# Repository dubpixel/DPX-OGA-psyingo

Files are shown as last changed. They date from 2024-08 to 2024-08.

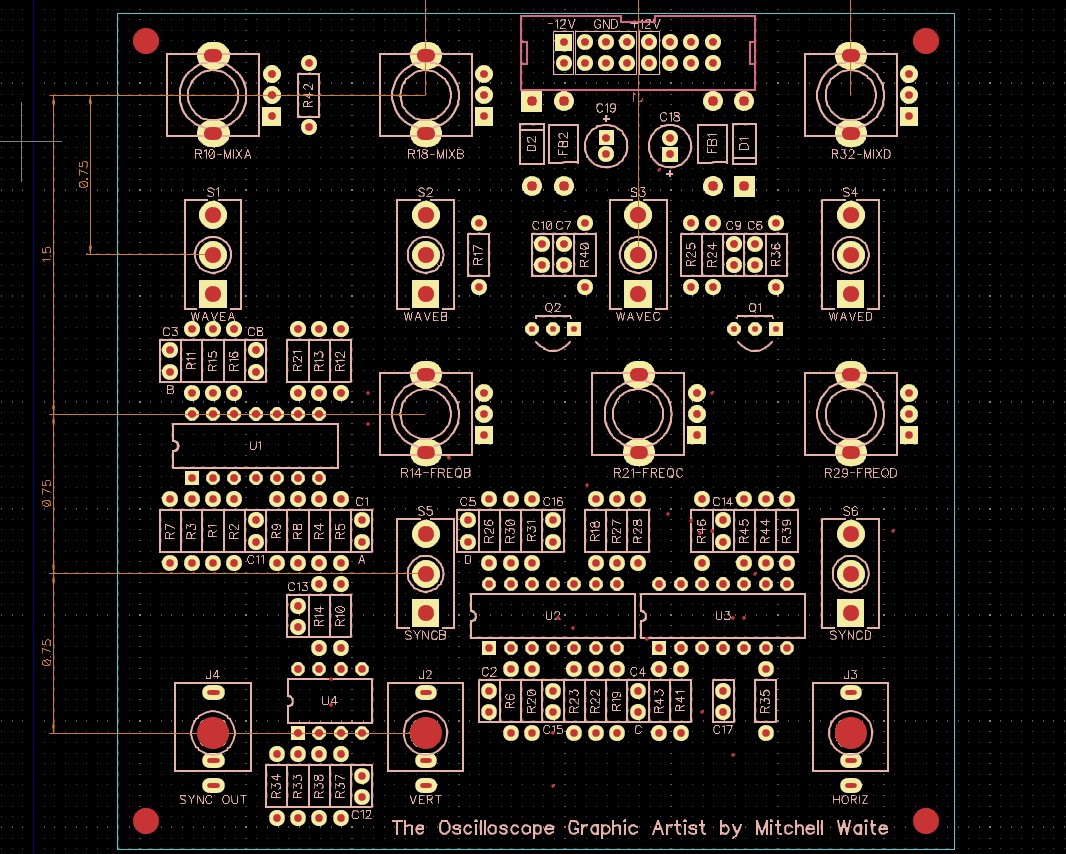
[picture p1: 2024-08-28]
doc/board_Screenshot_parts_placement.jpg

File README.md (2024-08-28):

# OGA

The Oscilloscope graphic artist is a project that was originally designed by Mitchell Waite in the November 1975 issue of Popular Electronics. 
I have made the design in to a PCB project with gerber files and a bill of materials for anyone to make. 
Please do not sell these for profit.
Contact me if you would like me to lead a workshop.
If you host your own workshop please credit me, Phil Baljeu. IG @pbalpbal [http:](https://www.instagram.com/pbalpbal/)https://www.instagram.com/pbalpbal/

#DPX
This fork includes a new panel + aims to add additional refinements towards using the device directly with ILDA lasers

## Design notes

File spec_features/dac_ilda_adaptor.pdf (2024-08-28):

This tutorial walks you through building a simple DAC_ILDA adaptor for converting audio signals sent from a multi-channel DAC (http://www.expert-sleepers.co.uk/siwacompatibility.html) (Digital Analog Converter) to an ILDA Interface (https://www.laserworld.com/en/show-laser-light-faq/glossary-definitions/79-i/1316-ilda-eng.html) (International Laser Display Association standard used for laser light systems) to control the XY-axis, RGB and intensity of the beam.

Warning: This is an amateur guide for interfacing an audio DAC with IDLA. Use at your own (+ laser) risk – each laser spec may have an custom requirements for voltage/frequency limiting needs. Be careful.

# DAC_ILDA Adaptor

v 0.1.2 // Download PDF (https://github.com/ffd8/dac_ilda/raw/master/dac_ilda_adaptor.pdf)

# Abstract

# Wiring Diagram

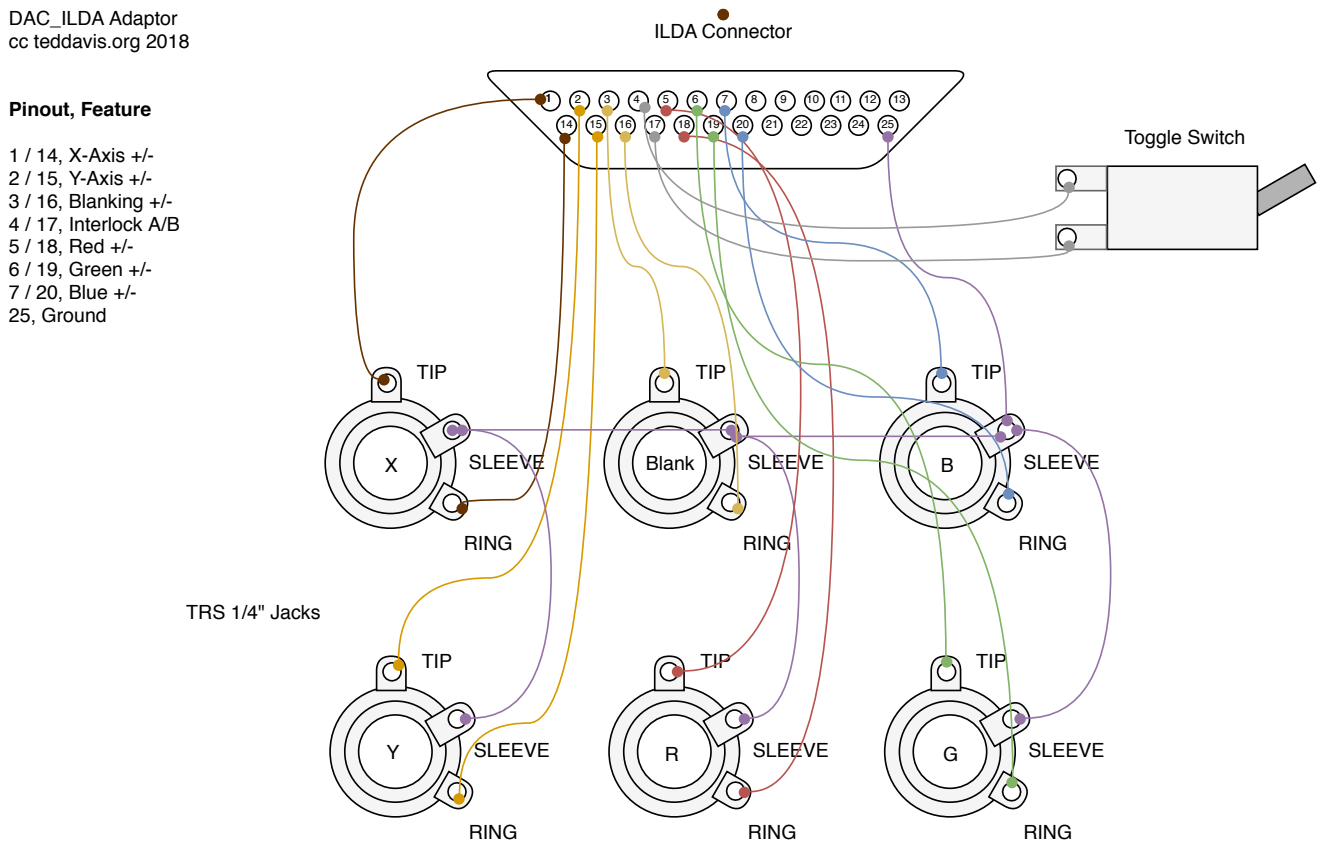
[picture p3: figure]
TIP; RING; Blank; SLEEVE; DAC_ILDA Adaptor cc teddavis.org 2018; Pinout, Feature; 1 / 14, X-Axis +/- 2 / 15, Y-Axis +/- 3 / 16, Blanking +/- 4 / 17, Interlock A/B 5 / 18, Red +/- 6 / 19, Green +/- 7 / 20, Blue +/- 25, Ground; ILDA Connector; TRS 1/4" Jacks; Toggle Switch

ILDA female connector (DB25)
6x 1/4" balanced (TRS) female jacks 6x 1/4" balanced (TRS) cables
1x toggle switch (on/off)
Various colored wires (jumper cables) Project box
Soldering iron + wire
Wirecutters

RGB Laser with ILDA interface
ILDA cable
DAC (multi-channel, balanced, ideally DC-Coupled outputs) Computer for producing audio signals

# Requirements

## Adaptor

## Setup

# Instructions

## 1 – Prep

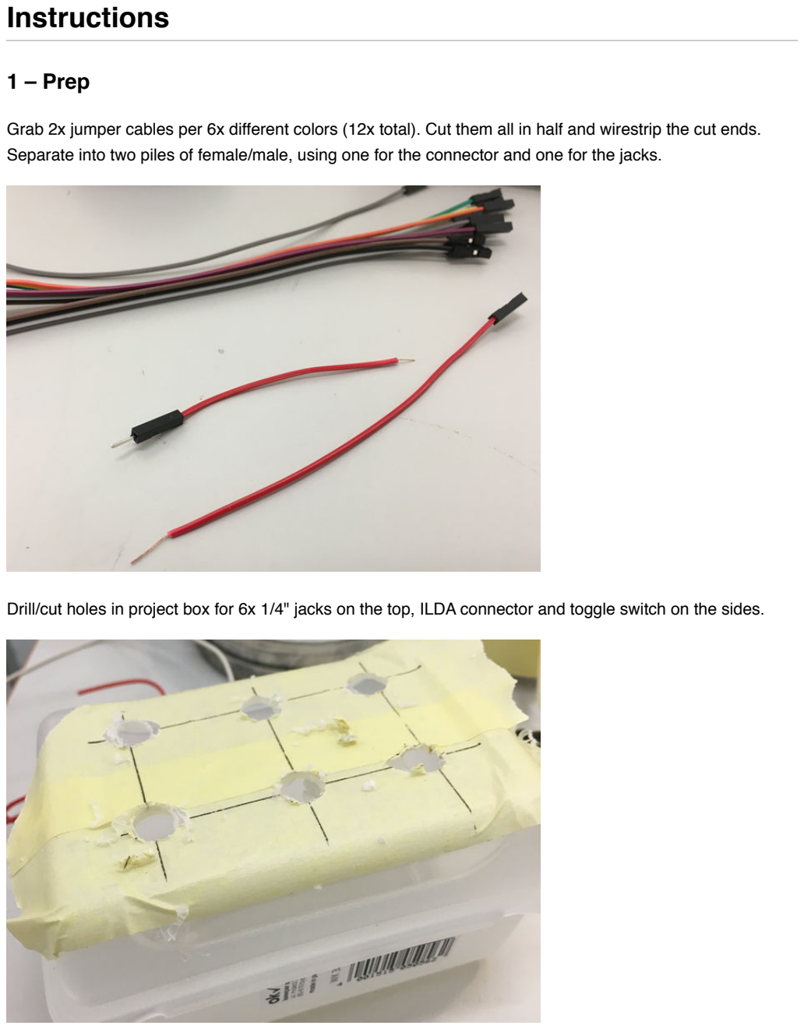
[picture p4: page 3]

Grab 2x jumper cables per 6x different colors (12x total). Cut them all in half and wirestrip the cut ends. Separate into two piles of female/male, using one for the connector and one for the jacks.

Drill/cut holes in project box for 6x 1/4" jacks on the top, ILDA connector and toggle switch on the sides.

Feature | Pins | Comment
X-Axis + / - | 1 / 14 | Horizontal movement, 10V
Y-Axis + / - | 2 / 15 | Vertical movement, 10V
Blanking + / - | 3 / 16 | Beam intensity, 5V
Interlock A / B | 4 / 17 | Enables output when joined
Red + / - | 5 / 18 | Red mixture, 5V
Green + / - | 6 / 19 | Green mixture, 5V
Blue + / - | 7 / 20 | Blue mixture, 5V
Ground | 25 | Connected to all jacks sleeve
Z-Axis | 11 / 24 | For DMX? See Blanking.

Note, 'Blanking' seems to be done via RGB values, rather than these ILDA pins.

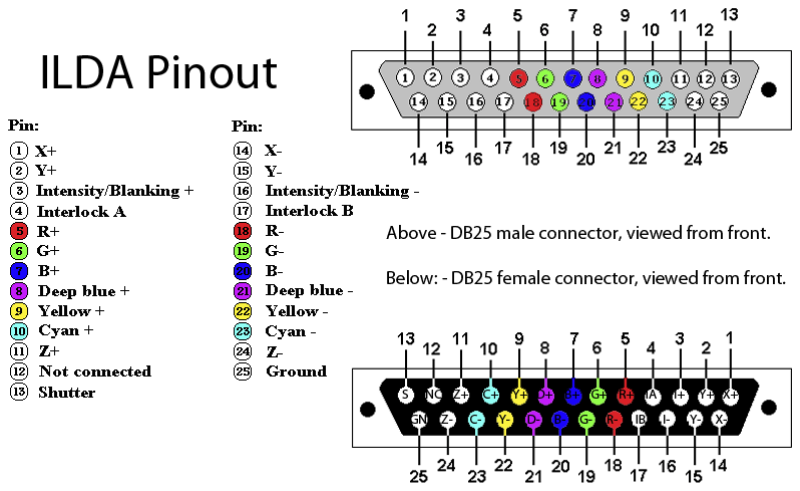
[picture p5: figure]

ILDA Pinout Source (https://vuo.org/comment/3145#comment-3145)

## 2 – ILDA Interface

Soldering paired color jumper cables to pins:

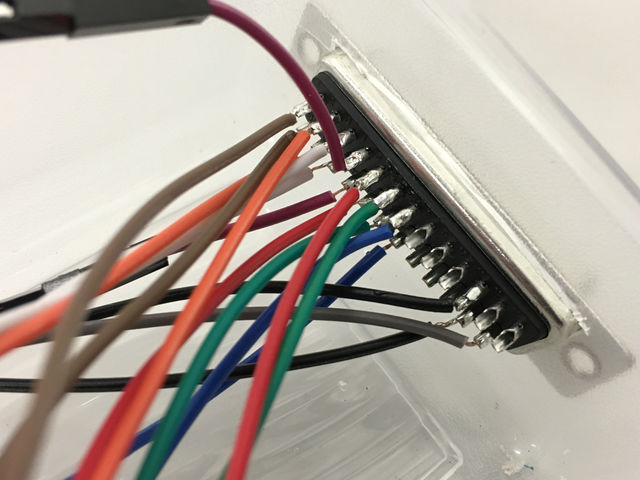
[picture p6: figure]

Diagram shows female ILDA connector from front, so flip pins horizontally when soldering to the back! I've already made that mistake for you...

Use different colored jumper cables per feature (8 total) to the diagram for easily identifying and patching the jacks to pins.

I wired jumpers to the Z-Axis pins (11/24), but not yet sure if they're needed.

Interlock A / B is a safety mechanism that only allows the laser to work if they're connected. I recommend using a basic toggle switch between these two pins.

Notes

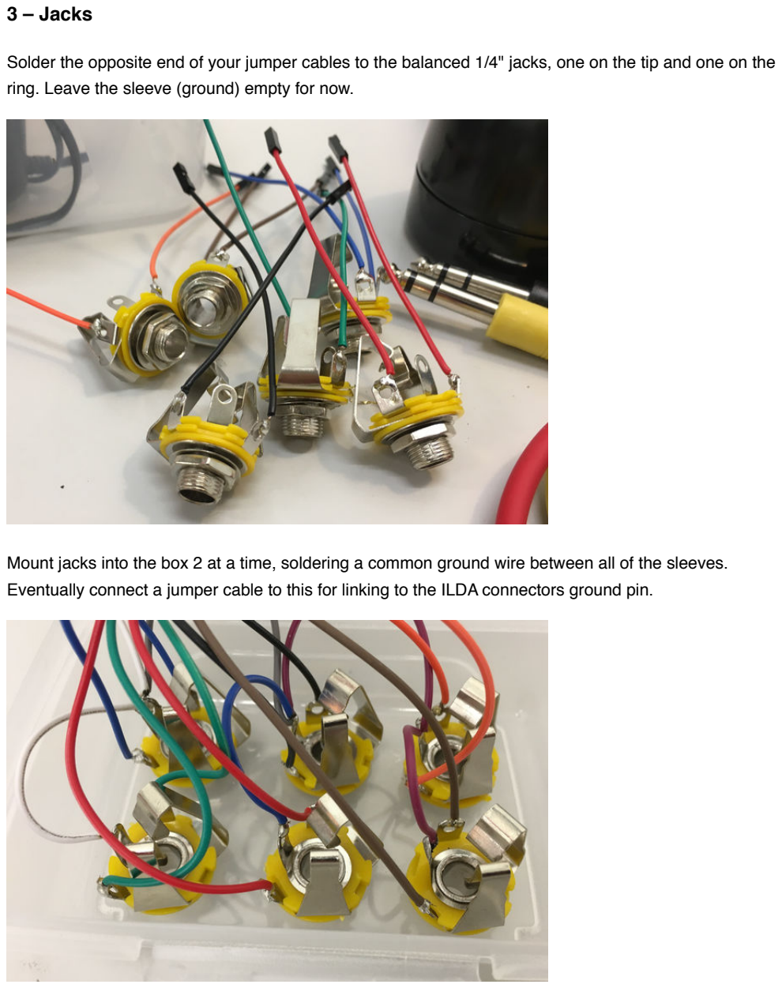
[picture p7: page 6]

Solder the opposite end of your jumper cables to the balanced 1/4" jacks, one on the tip and one on the ring. Leave the sleeve (ground) empty for now.

Mount jacks into the box 2 at a time, soldering a common ground wire between all of the sleeves. Eventually connect a jumper cable to this for linking to the ILDA connectors ground pin.

### 3 – Jacks

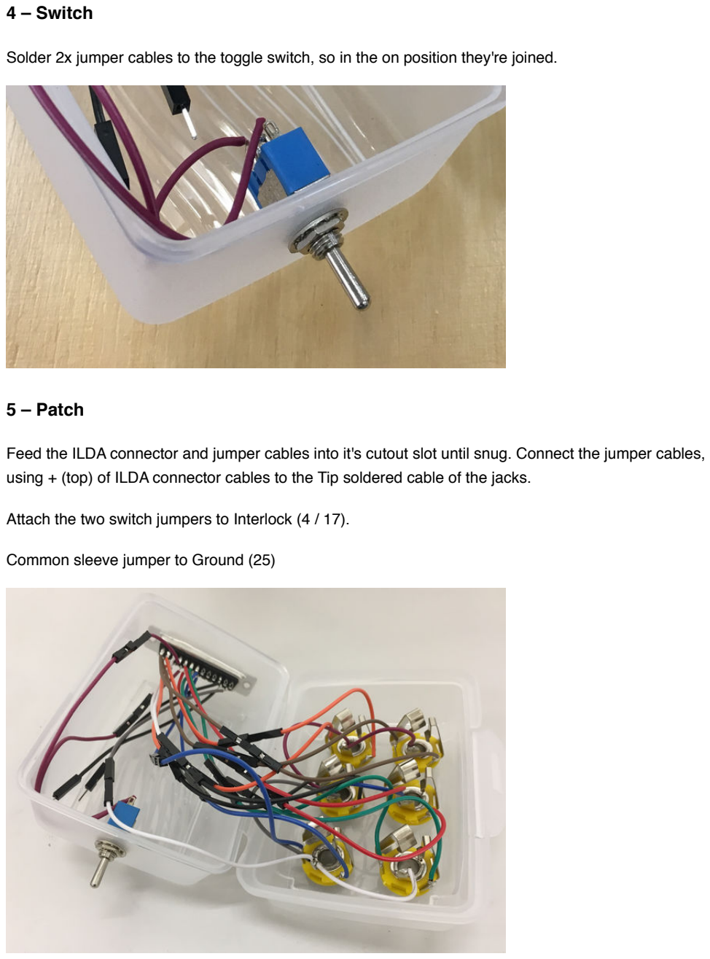
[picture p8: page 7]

Solder 2x jumper cables to the toggle switch, so in the on position they're joined.

Feed the ILDA connector and jumper cables into it's cutout slot until snug. Connect the jumper cables, using + (top) of ILDA connector cables to the Tip soldered cable of the jacks.

Attach the two switch jumpers to Interlock (4 / 17).

Common sleeve jumper to Ground (25)

### 4 – Switch

### 5 – Patch

Hook up your DAC » jacks + ILDA » laser and away you go!

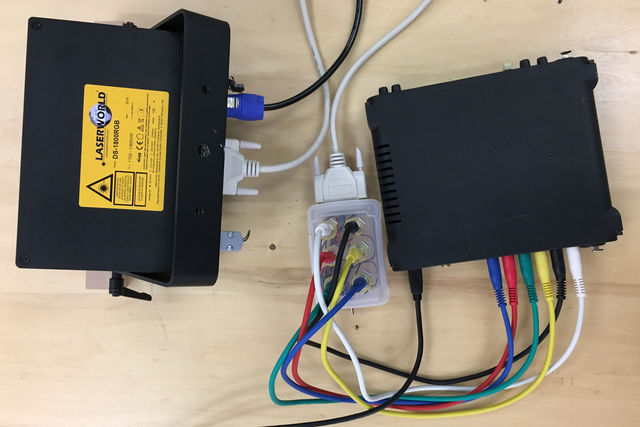
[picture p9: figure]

Here's a few tools to explore – some specific for laser, others for XY vector graphics +/- RGB capabilities:

Tool | Environment | OS | Cost | Realtime
LaserBoy (http://laserboy.org/) | Application | Windows | Free | -
LaserShow- Gen (http://pages.bitlasers.com/lasershowgen/) | Application | MacOS, Windows | Free Limited, $29.90 for Pro | √
Spaghetti Laser Show (http://www.spaghettilasershow.com/) | Application | Windows | $89.00 | √
LWave (https://www.photonlexicon.com/forums...896#post345896) | Application | Windows | Free | -
Tool | Environment | OS | Cost | Realtime | Laser
XYscope (http://teddavis.org/xyscope/) | Processing | MacOS, Windows, Linux | Free | √ | √
Vector Synthesis (http://macumbista.net/?page_id=4869) | PureData | MacOS, Windows, Linux | Free | √ | √
ReWereHere (http://i.m.klif.tv/rewerehere/) | Max/MSP | MacOS, Windows | Free | √ | √
OsciStudio (https://oscilloscopemusic.com/oscistudio.php) | Application | MacOS, Windows | €34 | √ | -

# Software

### Laser Specific

### Vector to Audio

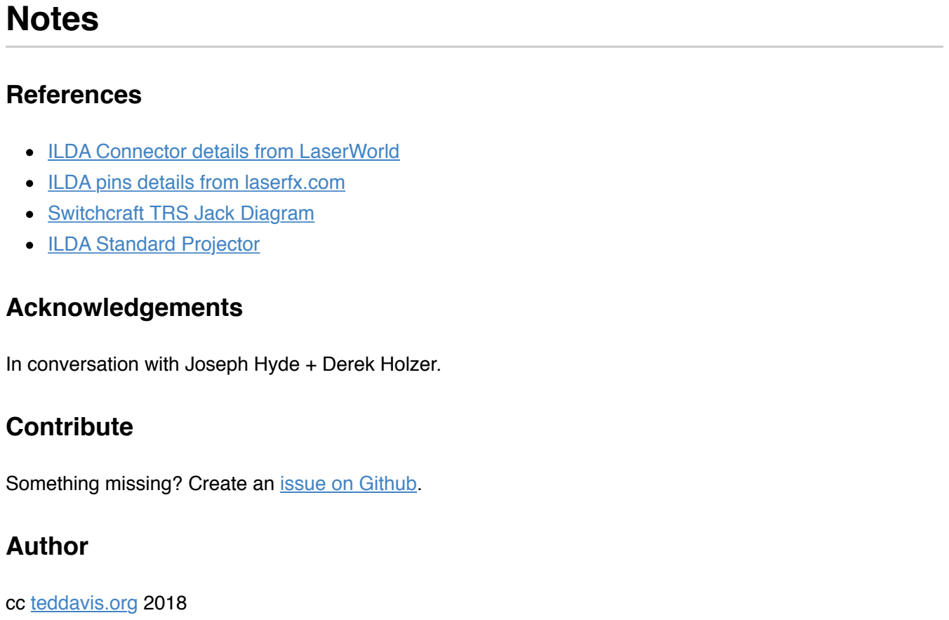
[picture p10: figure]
ILDA Connector details from LaserWorld; ILDA pins details from laserfx.com; Switchcraft TRS Jack Diagram; ILDA Standard Projector; cc teddavis.org 2018; Notes; References; Acknowledgements; Contribute; Author

In conversation with Joseph Hyde + Derek Holzer.

Something missing? Create an issue on Github. (https://github.com/ffd8/dac_ilda/issues)

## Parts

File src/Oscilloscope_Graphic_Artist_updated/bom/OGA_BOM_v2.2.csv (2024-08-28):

Ref | Value | Name | MFG | QTY | TAYDA | MOUSER | MOUSER ALT |  | Thonk | note | Lead Spacing
C1, C3 | 47n | CAP100 |  | 2 |  | 594-K473K20X7RH53H5 |  |  | XX | MLCC | 2.5
C2, C4, C10 | 1n | CAP100 |  | 3 |  | 594-K102K10X7RH5UL2 | 594-D102K29X5FL63L6R |  | XX |  | 2.5
C5, C6, C7, C8, C11, C12, C13, C14, C15, C16, C17 | 100n | CAP100 |  | 11 |  | 594-K104K15X7RF5TH5 |  |  | XX |  | 2.5
C9 | 10n | CAP100 |  | 1 |  | 594-K103K10X7RF5UL2 | 594-S103M47Z5UN63J7R |  | XX |  | 2.5
C18, C19 | 10u 25V | EC80-5 |  | 2 |  | 667-ECA-1EM100I |  |  | XX |  | 2.5
D1, D2 |  | 1N4001 |  | 2 |  | 625-1N4001-E3/73 |  |  | XX
FB1, FB2 | 68R | Ferrite Bead | Fair-Rite | 2 |  | 623-2743001112LF |  |  | XX
J1 |  | EUROPWR16 |  | 1 | A-2956 | 710-61201621621 |  |  | XX
Q1, Q2 |  | 2N3819 | ON Semiconductor | 2 |  | 610-2N3819 |  |  | XX
R1, R3, R7, R11, R13, R17, R19, R26, R28, R30, R33, R34, R35, R37, R38, R39, R41, R42, R43, R44, R45, R46 | 10K | RES300 |  | 22 | A-2203 | 660-MF1/4DCT52R1002F | 660-MF1/4DCT52A1002F |  | XX |  | 7.5
R2, R12, R27 | 20K | RES300 |  | 3 |  | 660-MF1/4DCT52R2002F | 660-MF1/4DCT52A2002F |  | XX |  | 7.5
R4, R25 | 4.7K | RES300 |  | 2 |  | 660-MF1/4DCT52R4701F | 660-MF1/4DC4701F |  | XX |  | 7.5
R5, R6, R9, R10, R14, R18, R21 | 1K | RES300 |  | 7 | A-2200 | 660-MF1/4DCT52R1001F |  |  | XX |  | 7.5
R8 | 120K | RES300 |  | 1 |  | 660-MF1/4DCT52R1203F |  |  | XX |  | 7.5
R15 | 24K | RES300 |  | 1 |  | 660-MF1/4DCT52R2402F |  |  | XX |  | 7.5
R16, R23, R31 | 100K | RES300 |  | 3 |  | 660-MF1/4D52R1003F |  |  | XX |  | 7.5
R20 | 15K | RES300 |  | 1 |  | 660-MF1/4DCT52R1502F |  |  | XX |  | 7.5
R22 | 2.7K | RES300 |  | 1 |  | 660-MF1/4DCT52R2701F |  |  | XX |  | 7.5
R24 | 47K | RES300 |  | 1 | A-2279 | 660-MF1/4DCT52R4702F |  |  | XX |  | 7.5
R36, R40 | 470K | RES300 |  | 2 | A-2180 | 660-MF1/4DCT52R4703F |  |  | XX |  | 7.5
R10-MIXA, R18-MIXB, R32-MIXD | B10K | ALPHA9V | Alpha | 3 | A-5531 | 652-PTV09A4020SB103 | 311-1940F-15R1-B10K |  | alpha 9mm pots vertical | linear
R14-FREQB, R21-FREQC, R29-FREQD | 1M | ALPHA9V | Alpha | 3 |  | 652-PTV09A4020SB105 | 317-3090F-B1M |  | alpha 9mm pots vertical | linear?
S1, S2, S3, S4, S5, S6 | WAVEA-D, SYNC B-D | 7101K2CBE | C&K | 6 |  | 612-100-A1421 | 612-100-A1122 | 611-7101-002 | DWB1 | og part specd here seems wrong - k2 Is wrong toggle type-
U1, U2, U3 |  | TL074J | Texas Instruments | 3 |  | 595-TL074CN | 595-TL074CN |  | xx
U4 |  | TL072P | Texas Instruments | 1 |  | 595-TL072CP | 595-TL072CP |  | xx
J2 | VERT | WQP-PJ398SM | Wenzhou QingPu Electronics Co., Ltd | 1 | A-2563 | XX |  |  | THONKICONN NEW - PJ398SM
J3 | HORIZ | WQP-PJ398SM | Wenzhou QingPu Electronics Co., Ltd | 1 | A-2563 | XX |  |  | THONKICONN NEW - PJ398SM
J4 | SYNC OUT | WQP-PJ398SM | Wenzhou QingPu Electronics Co., Ltd | 1 | A-2563 | XX |  |  | THONKICONN NEW - PJ398SM

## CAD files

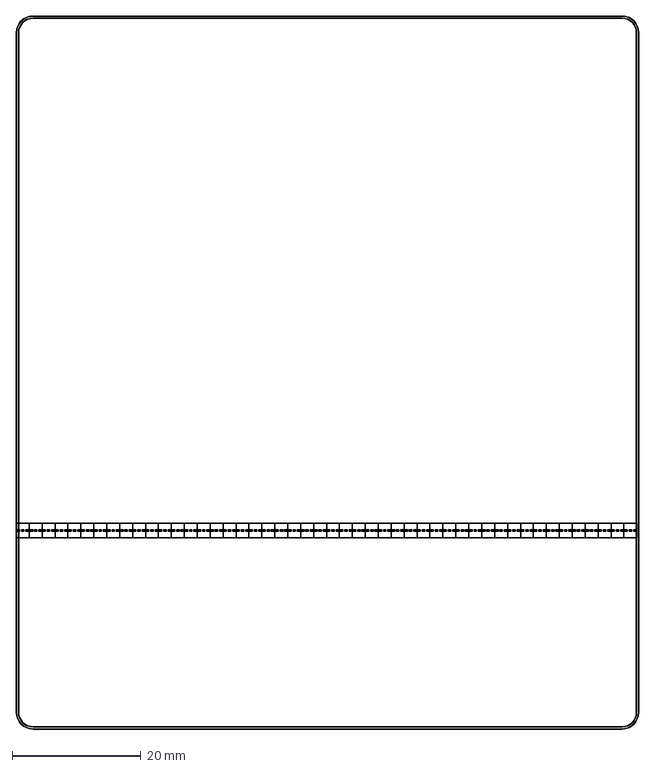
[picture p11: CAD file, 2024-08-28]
src/Oscilloscope_Graphic_Artist_Panel/DPX_v002/design/artwork/dxf_layer/004_oga_border.dxf
96.6 x 110.7 mm

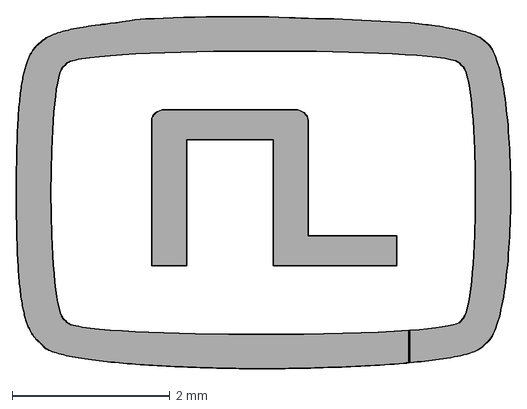
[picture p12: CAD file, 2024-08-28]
src/Oscilloscope_Graphic_Artist_Panel/DPX_v002/design/artwork/FRAME_TEST_1.dxf
6.27 x 4.47 mm

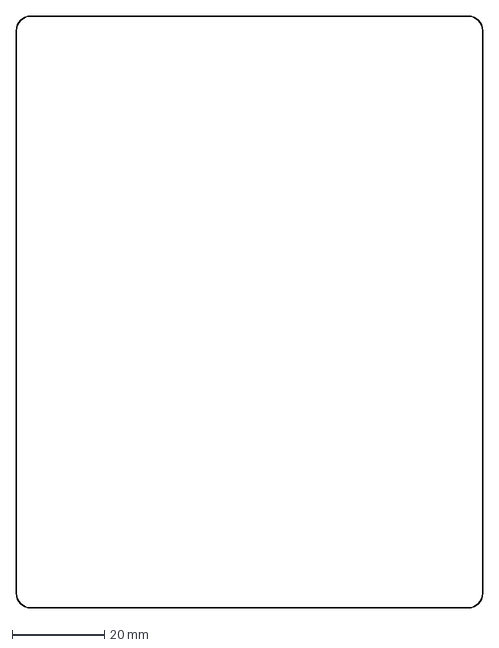
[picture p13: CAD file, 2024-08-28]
src/Oscilloscope_Graphic_Artist_Panel/DPX_v002/design/artwork/dxf_layer/001_oga_panel_2.dxf
101.3 x 128.5 mm

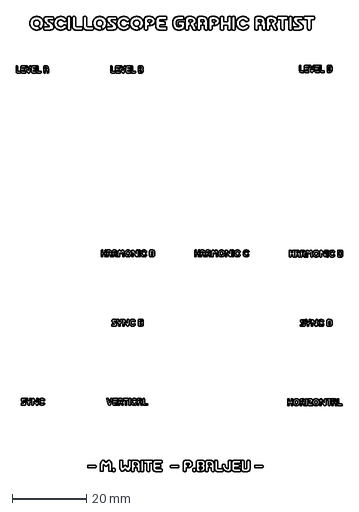
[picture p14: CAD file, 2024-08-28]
src/Oscilloscope_Graphic_Artist_Panel/DPX_v002/design/artwork/dxf_layer/005_oga_txt.dxf
87.8 x 122.2 mm

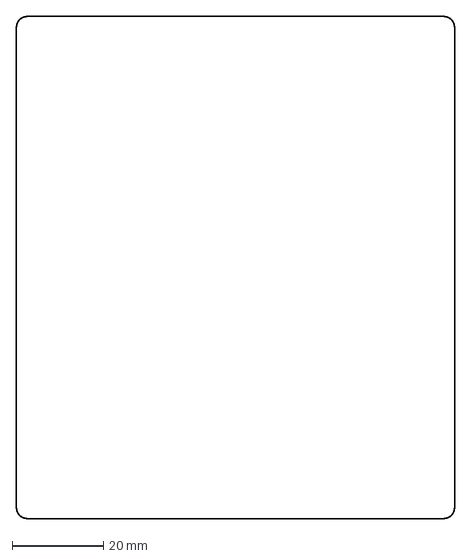
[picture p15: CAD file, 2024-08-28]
src/Oscilloscope_Graphic_Artist_Panel/DPX_v002/design/artwork/dxf_layer/004_oga_border_line.dxf
96.2 x 110.3 mm

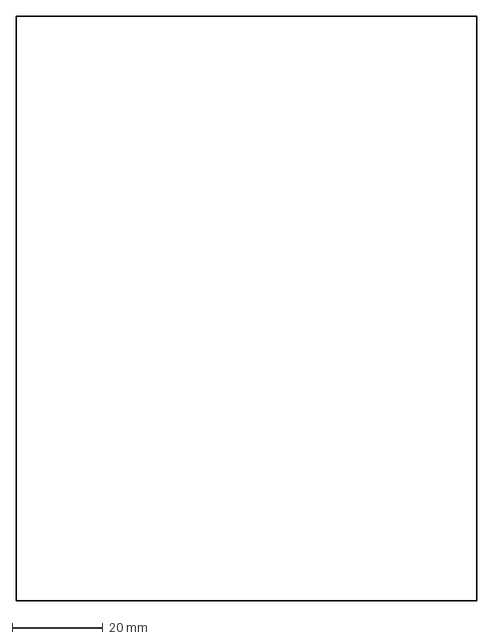
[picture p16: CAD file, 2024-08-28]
src/Oscilloscope_Graphic_Artist_Panel/DPX_v002/design/artwork/dxf_layer/001_oga_panel.dxf
101.3 x 128.5 mm

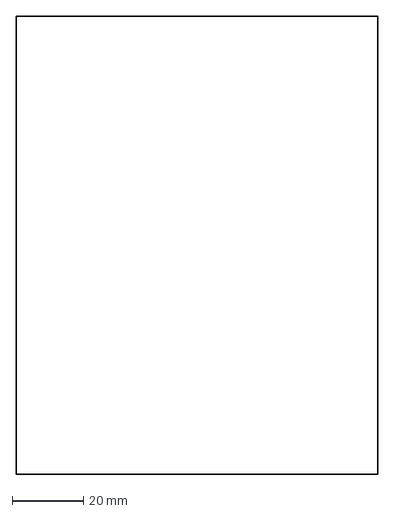
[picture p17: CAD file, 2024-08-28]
src/Oscilloscope_Graphic_Artist_Panel/DPX_v002/design/artwork/dxf_layer/001_oga_panel_3.dxf
101.3 x 128.5 mm

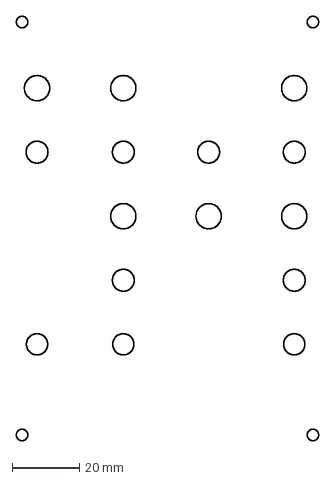
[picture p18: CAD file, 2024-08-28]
src/Oscilloscope_Graphic_Artist_Panel/DPX_v002/design/artwork/dxf_layer/002_oga_holes.dxf
89.7 x 125.9 mm

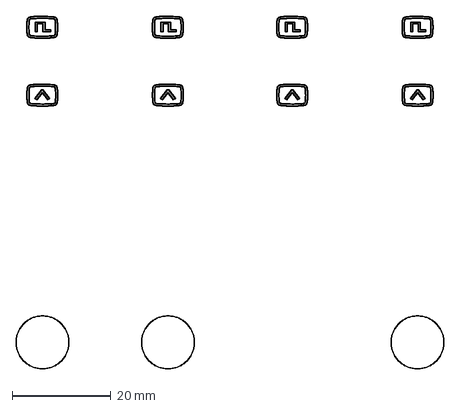
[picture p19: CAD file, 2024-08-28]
src/Oscilloscope_Graphic_Artist_Panel/DPX_v002/design/artwork/dxf_layer/003_oga_gfx.dxf
86.9 x 71.6 mm

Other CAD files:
src/Oscilloscope_Graphic_Artist_Panel/OGA PANEL.dxf
src/Oscilloscope_Graphic_Artist_Panel/DPX_v002/design/artwork/oga_v002.dxf

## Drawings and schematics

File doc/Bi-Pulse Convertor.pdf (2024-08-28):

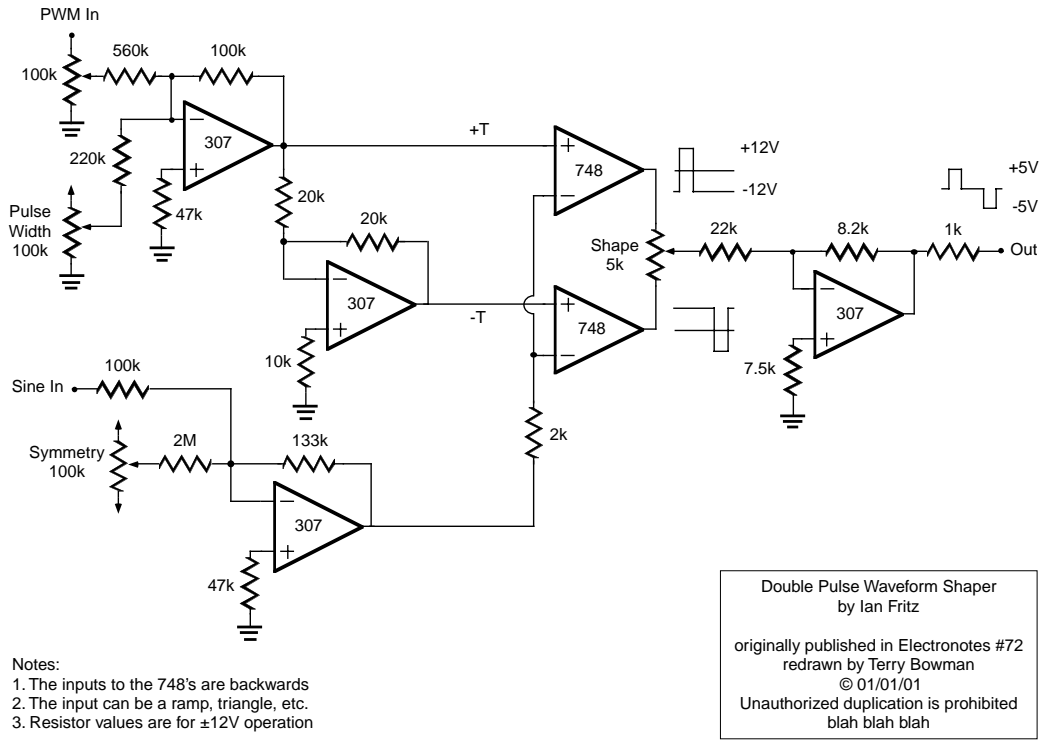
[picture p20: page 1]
PWM In; Sine In; Shape 5k; Out; Pulse; Width 100k; Symmetry 100k

Double Pulse Waveform Shaper

by Ian Fritz

originally published in Electronotes #72
redrawn by Terry Bowman

Notes:
1. The inputs to the 748’s are backwards
2. The input can be a ramp, triangle, etc.
3. Resistor values are for ±12V operation

Unauthorized duplication is prohibited

blah blah blah

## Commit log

2023-08-29 add new panel version 002
    [001_oga_panel.dxf, 001_oga_panel_2.dxf, 001_oga_panel_3.dxf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]
2024-08-28 Big Push & reorg - Not Including panel Gerbers
    didnt include panel gerbers at phil's request. hes worried about getting ripped off.
    [001_oga_panel.dxf, 001_oga_panel_2.dxf, 001_oga_panel_3.dxf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]
